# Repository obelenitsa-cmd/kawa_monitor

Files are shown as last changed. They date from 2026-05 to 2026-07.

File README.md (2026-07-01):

# kawa_monitor
Индикатор для Kawasaki на ESP32-S3 LCD 1.47. 

ВНИМАНИЕ! Проект не является полностью готовым к использованию!

Индикатор отображает:
— Текущая передача (из ECU)
— Температура ДВС (из ECU)
— Напряжение (из ECU)
— Bluetooth датчики давления шин (TPMS)

Для отображения информации использовал ESP32-S3 c LCD монитором 1.47 дюйма.
Текущую передачу, температуру ДВС и напряжение получаем по K-line из ECU, датчики давления передают информацию по Bluetooth, который имеется на борту ESP32-S3 LCD 1.47, 
ну а WiFi, который так же есть на борту ESP32-S3 LCD 1.47 решил использовать для беспроводного обновления ПО в случае необходимости, что бы не снимать монитор с мото для перепрограммирования.
Так же добавил фототранзистор и функцию автоматического затемнения экрана (по ШИМ), что бы в темноте (ночью) сильно не светился, а на солнце была максимальная яркость. 
При этом заменил оригинальное сопротивление ограничивающее ток подсветки с 10 Ом на 4,7 Ом, чем увеличил максимальную яркость.



Параметры ESP32-S3:

Arduino_IDE_Tools

Обратил внимание, что заднее колесо считывается несколько реже, оказалось, что проблемма в антенне ESP32-S3 LCD 1.47 (не отличающаяся соей высокой дальностьтью изначально ;-) ), т.к. заднее колесо находится дальше от монитора чем переднее + элетромагнитные помехи мотоцикла и DC-DC преобразователя влияют на принимаемый сигнал.
Качество сигнала RSSI значительно улучшилось после:
- Установки Ферритового фильтра на кабель максимально близко к ESP32-S3 LCD 1.47 для устранения "шума" от импульсного DC-DC преобразователя CN3903.
- Добавление конденсаторов 4,7 мкф и 0,1 мкф на плату ESP32-S3
- Программно изменил опрос BLE на почти постоянный, для увеличения вероятности "поймать" сигнал.
- Модифицикации антенны.

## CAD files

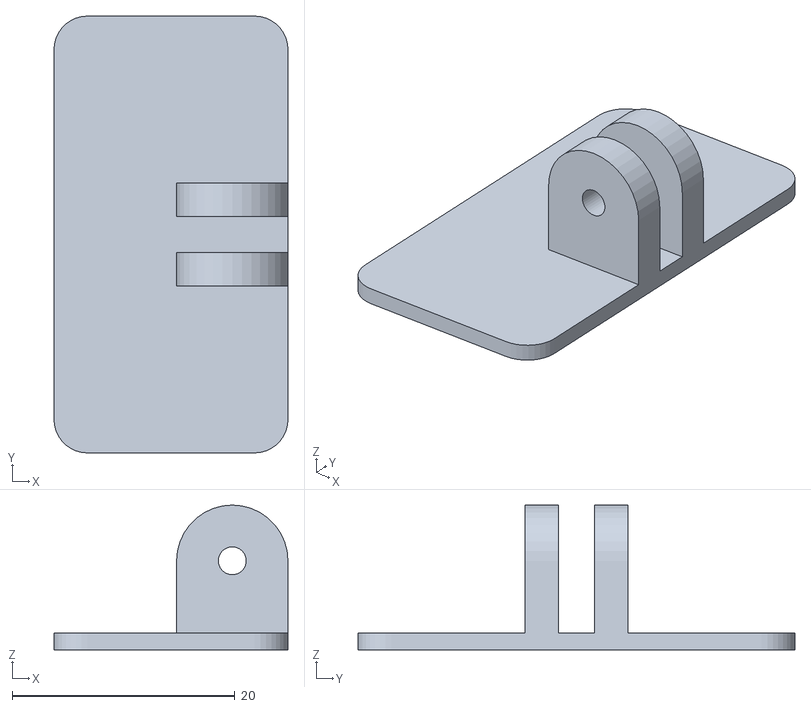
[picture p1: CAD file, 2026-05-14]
monitor_3D/Hingle_to_glass.STL
21.0 x 39.2 x 13.0

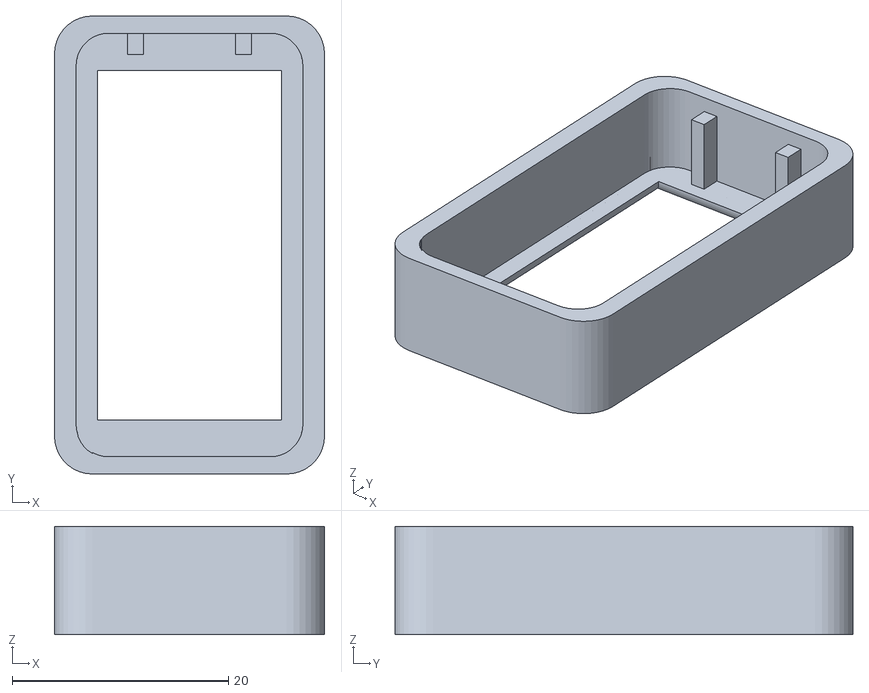
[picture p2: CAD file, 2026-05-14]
monitor_3D/Box.STL
25.0 x 42.4 x 10.0

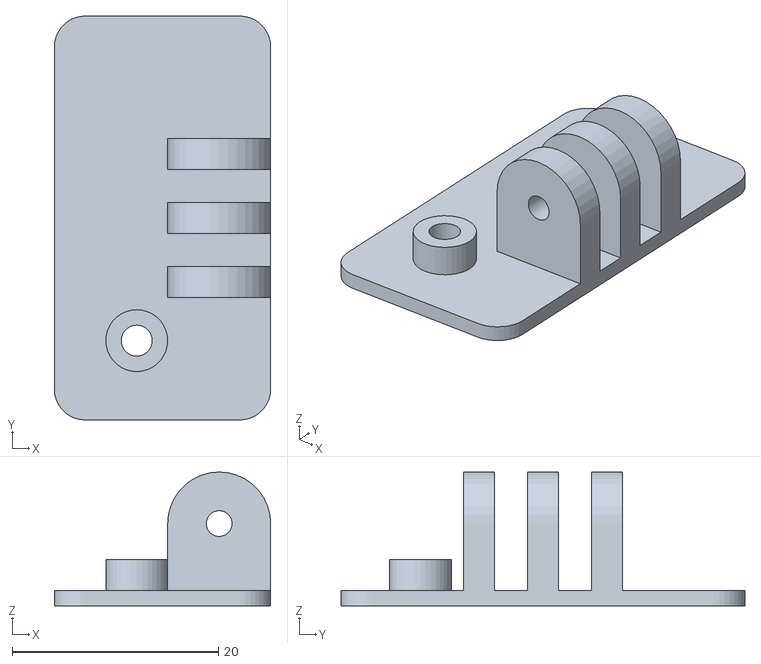
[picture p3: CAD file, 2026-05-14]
monitor_3D/Hingle_box.STL
21.0 x 39.2 x 13.0

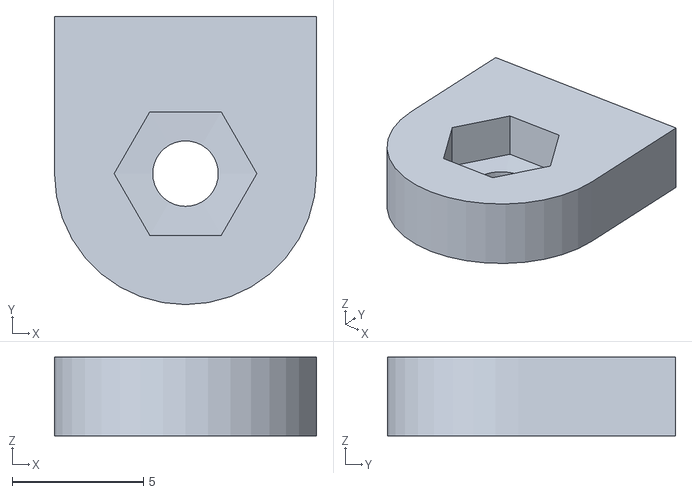
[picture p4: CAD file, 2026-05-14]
monitor_3D/Screw_nut.STL
10.0 x 11.0 x 3.00

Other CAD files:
monitor_3D/Screw_head.STL

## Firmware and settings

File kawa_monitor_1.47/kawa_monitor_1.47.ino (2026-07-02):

TaskHandle_t Task1;
TaskHandle_t Task2;

void Task1code(void *parameter) {
  for (;;) {  // бесконечный цикл 
   LoopOTAWiFi();
   LoopBLE_TPMS();
   vTaskDelay(1);
  }
}

void Task2code(void *parameter) {
  for (;;) {  // бесконечный цикл
   LoopKline(); 
   vTaskDelay(1);
  }
}

void setup() {
  //Serial.begin(115200);
  SetupDisplay();
  SetupOTAWiFi();
  SetupBLE_TPMS();

  xTaskCreatePinnedToCore(Task1code, "Task1", 8192, NULL, 1, &Task1, 0 ); //Ядро 0 (4096 - периодически может происходить переполнение)
  delay(1);
  xTaskCreatePinnedToCore(Task2code, "Task2", 6144, NULL, 1, &Task2, 1); //Ядро 1  
}

void loop() {       
   LoopDisplay();
   delay(1);
}

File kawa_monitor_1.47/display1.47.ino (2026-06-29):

#include <Arduino_GFX_Library.h>
#include "DotDigital12.h"
#include "global_flags.h"
//====================================================================== если ESP32-S3 LCD 1.47 Touch  ==========================
//#define GFX_BL 46
//#define LCD_RST  40

//#define Touch_I2C_SDA 42
//#define Touch_I2C_SCL 41
//#define Touch_RST     47
//#define Touch_INT     48

//Arduino_DataBus *bus = new Arduino_ESP32SPI(45, 21, 38, 39);
//Arduino_GFX *gfx = new Arduino_ST7789(bus, LCD_RST, 5, false, 172, 320, 34, 0, 34, 0);

              //============ RGB-565 (16-bit) для моего ESP32-S3 LCD 1.47 Touch
//#define BLACK   0x0000   // Черный 
//#define WHITE   0xFFFF   // Белый 
//#define YELLOW  0x07FF   // ЖЕЛТЫЙ
//#define GREEN   0xAFE6   // ЗЕЛЕНЫЙ

//#define PIN_PHOTO 7
//====================================================================== если ESP32-S3 LCD 1.47 No Touch ==========================
#define GFX_CS      42
#define GFX_RST     39
#define GFX_BL      48       // if DF_GFX_BL - default backlight pin

Arduino_DataBus *bus = new Arduino_ESP32SPI( 41, 42, 40, 45, -1, FSPI );
Arduino_GFX *gfx = new Arduino_ST7789( bus, 39, 1, true, 172, 320, 34, 0, 34, 0); 
  //============ RGB-565 (16-bit)
#define BLACK 0x0000
#define WHITE 0xFFFF
#define YELLOW	0xFFE0
#define GREEN 0xAFE6

//#define GREEN2 0x07E0
//#define LIME 0x67E0
//#define CADMIUM_YELLOW	0xFFA0

#define PIN_PHOTO 6
//======================================================================

uint8_t geardata;
float FW_bar, new_FW_bar, RW_bar, new_RW_bar;
bool OtaOn = false;
bool OnECU = true;

uint32_t blinkTimer = 0;
bool showBatteryIcon = false;

//Динамическая подсвека от фотоэлемента для N-P-N транзистора GPIO подтянут к "+" эмиттер к GND
// Параметры фильтрации
float filtered_light = 4095;
// При частоте опроса 5 Гц (каждые 200 мс - см. LoopPHOTO()) коэффициент 0.06 
// дает плавную адаптацию яркости за 2.5 секунды.
const float filter_k = 0.4; // Коэффициент сглаживания (0.01 - медленно, 1 - быстро)
int new_pwm_brightness = 4095;
int minpwm = 32; //минимальное значение ШИМ подсветки
int raw_light, pwm_brightness;

void SetupDisplay() {
 #ifdef DEV_DEVICE_INIT
  DEV_DEVICE_INIT();
 #endif
 //==================== Подсвека ==================
  pinMode(GFX_BL, OUTPUT);
  //digitalWrite(GFX_BL, HIGH); // Дискретная подсветка
  //analogWrite(GFX_BL, 255); // ШИМ подсветки 0-255
  // Поднимаем частоту ШИМ на пине до 15 кГц. (убераем любые наводки по питанию на фототранзистор.)
  analogWriteFrequency(GFX_BL, 15000); // ШИМ подсветка, частота

  // Вход фототранзистора (коллектор) к 3.3В через дополнительное сопротивление 10кОм (с внутренней плдтяжкой -INPUT_PULLUP) или 8кОм (без внутренней плдтяжки)
  //pinMode(PIN_PHOTO, INPUT_PULLUP); 
  pinMode(PIN_PHOTO, INPUT); 

  filtered_light = analogRead(PIN_PHOTO); // Начальная инициализация фильтра средним значением

  // ******************Init Display**************
  gfx->begin(); 
  gfx->fillScreen(BLACK);

  gfx->setFont(); 
  gfx->setTextColor(WHITE, BLACK);
  gfx->setTextSize(3, 4, 2 ); //TPMS
  gfx->setCursor(12, 71); // TPMS
  gfx->print("bar"); // TPMS
  gfx->setCursor(301, 46); // Напряжение
  gfx->print("v"); // Напряжение
  gfx->setCursor(301, 95); // Температура
  gfx->print("c"); // Температура
  gfx->drawCircle(295, 100, 1, WHITE); // Температура, символ градус
}

void LoopDisplay() {

 float voltdata, newvolt;
 int tempdata, newtemp;

 char buffer[4][8]; // Создаем 4 буфера, каждый размером по 8 байт
 char clean_buffer[4][8] = {0}; // Инициализация нулями при объявлении

  //НЕБЛОКИРУЮЩИЙ ТАЙМЕР МИГАНИЯ (500 мс / 500 мс)
  bool toggleBlink = false;
  if (millis() - blinkTimer >= 500) {
    blinkTimer = millis();
    showBatteryIcon = !showBatteryIcon; // Меняем состояние (давление <-> батарейка)
    toggleBlink = true;                 // Флаг, что пора принудительно обновить экран
  }

  // ================================================если нет или потеряно подключение к ECU
  if (OnECU != ECUconnected){  // обновление данных только если данные изменились
    if (!ECUconnected){ 
      gfx->setFont(); 
      gfx->setTextColor(WHITE, BLACK);
      gfx->setTextSize(4, 5, 2 );
      //==============No Volt
      gfx->setCursor(224, 11);
      gfx->print("    ");
      //==============No Temp
      gfx->setCursor(248, 132);
      gfx->print("    ");
      delay(1);
    }
    OnECU = ECUconnected;
  }
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
